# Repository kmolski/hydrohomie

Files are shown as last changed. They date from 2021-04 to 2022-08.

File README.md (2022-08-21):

# hydrohomie

The smart drink coaster that lets you gather, view and analyze data on your water drinking habits.

The coaster device, based on the ESP32 MCU, uses a load sensor to measure the volume of water consumed,
which is then (optionally) sent over Wi-Fi & MQTT to the web application for storage and presentation purposes.

This started out as my 5th semester project for the Microprocessor and Embedded Systems course, for which I
prepared the hardware and firmware components. The web application was created later, primarily as a means to
get some practice with new Java features and popular libraries, like Spring Integration/Security and Mockito.

Project components
------------------

- [Hardware](./hardware) - board & logic schematics in PDF & Autodesk EAGLE files
- [Firmware](./firmware) - firmware for the ESP32 chip, based on the Arduino platform
- [Web application](./web-app) - (optional) Spring Boot web app, provides coaster management & data visualization functionality

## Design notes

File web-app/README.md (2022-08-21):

# hydrohomie - web application


Coverage (https://github.com/kmolski/hydrohomie/actions/workflows/gradle.yml)

Companion web app for the smart coaster device, built with Java 17 and open-source tools.

This application is entirely optional. The smart coaster can function without it, although with
slightly limited functionality (e.g. no measurement/daily total persistence between device restarts).

For more details about the application structure, view the [JavaDocs](https://kmolski.github.io/hydrohomie/docs/).

<p style="text-align: center;">
<table style="padding: 0px; border-spacing: 0px;">
    <tr>
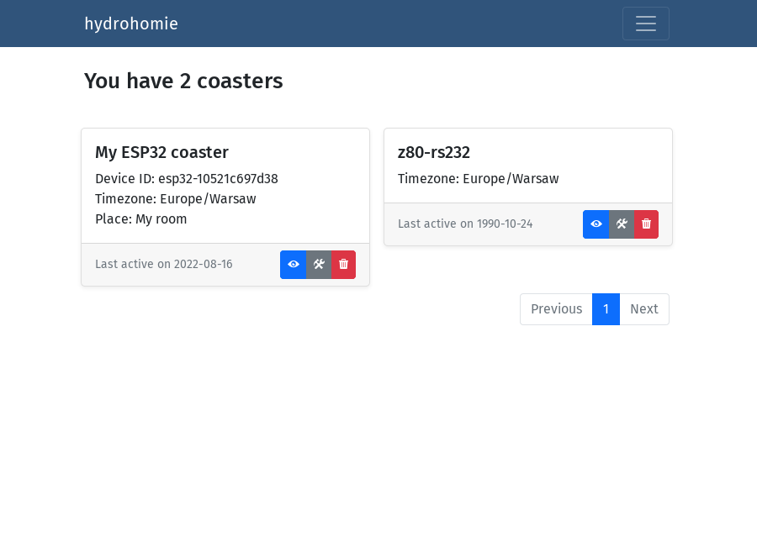
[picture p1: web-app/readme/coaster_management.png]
        <th scope="col"></th>
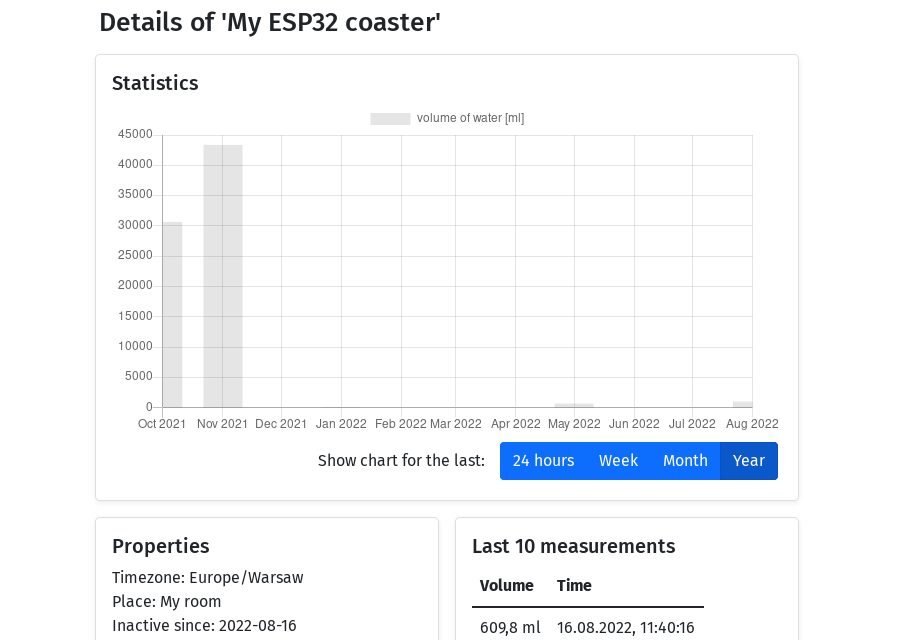
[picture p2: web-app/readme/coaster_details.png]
        <th scope="col"></th>
    </tr>
    <tr>
        <th scope="col">Coaster management</th>
        <th scope="col">Coaster details view</th>
    </tr>
</table>
</p>

Configuration
-------------

| Environment variable | Spring property name | Default value | Description |
|---|---|---|---|
| `ADMIN_USER` | `admin.username` | _(none)_ | Admin account username |
| `ADMIN_PASS` | `admin.password` | _(none)_ | Admin account password |
| `MQTT_URL` | `mqtt.url` | _(none)_ | MQTT broker URL |
| `MQTT_CLIENT_ID` | `mqtt.client-id` | `backend` | MQTT client ID prefix |
| `MQTT_TOPIC` | `mqtt.topic` | `hydrohomie`  | MQTT topic prefix |
| `DB_HOST` | _(none)_ | _(none)_ | PostgreSQL instance hostname |
| `DB_NAME` | _(none)_ | _(none)_ | PostgreSQL database name |
| `DB_USER` | _(none)_ | _(none)_ | PostgreSQL account username  |
| `DB_PASS` | _(none)_ | _(none)_ | PostgreSQL account password  |

Quick setup with docker-compose
-----------

### Build Docker container

```cmd
$ ./gradlew bootBuildImage
```

### Run with docker-compose

__This method uses `admin/admin` as the default admin account credentials.__

```cmd
$ docker-compose up -d
```

The application will be available at `http://localhost:8080`.

First steps
-----------

1. Log in with the admin account
2. Create a new application user 
3. Turn the coaster on & go to the "Coasters" tab
4. Click "Assign" to start the assignment procedure
5. Choose the user account to assign the coaster to
6. Log in with the application user account

Dependencies
------------

- [Spring Boot](https://spring.io/projects/spring-boot) - configuration & monitoring
- [Spring WebFlux](https://docs.spring.io/spring-framework/docs/current/reference/html/web-reactive.html) - reactive Web MVC framework
- [Spring Security](https://spring.io/projects/spring-security) - authentication & access control
- [Spring Integration](https://spring.io/projects/spring-integration) + [Paho client](https://www.eclipse.org/paho) - MQTT communication
- [Thymeleaf](https://www.thymeleaf.org) + [Bootstrap](https://getbootstrap.com) - HTML templates & CSS framework
- [Spring Data R2DBC](https://spring.io/projects/spring-data-r2dbc) + [PostgreSQL](https://www.postgresql.org) - object mapper & RDBMS
- [JUnit 5](https://junit.org/junit5) + [Mockito](https://site.mockito.org) - integration & unit test tools
- [Testcontainers](https://www.testcontainers.org) - containers for integration tests
- [Liquibase](https://www.liquibase.org) - database migration tool
- [Lombok](https://projectlombok.org) - code generation library

License
-------

[MIT License](https://opensource.org/licenses/MIT)

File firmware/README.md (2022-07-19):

# hydrohomie - firmware

Firmware for the smart coaster device, based on the Arduino ESP32 platform and open-source libraries.

Setup instructions
-----------

### Load cell calibration
1. Configure the target device in `platformio.ini`.
2. Uncomment the load cell calibration code at `src/embedded.cpp:163-171`.
3. Build & flash the device with `pio run -t upload`.
4. Wait for the device to start and press S1 with a known weight on the coaster.
5. Write down the value shown on the LCD screen as "x".
6. Calculate the load cell scale as `x / m`, where "m" is the known weight in grams.
7. Set the load cell scale in `include/config.h`.
8. Comment/remove the load cell calibration code.

### Wi-Fi and MQTT configuration
9. Set the Wi-Fi SSID, Wi-Fi password, MQTT broker IP and MQTT topic in `include/secrets.h`.
10. Adjust the maximum inactivity time in `include/config.h`.

### Firmware flashing
11. Build & flash the device with `pio run -t upload`.

Dependencies
------------

- [PlatformIO toolset](https://platformio.org)
- [Arduino ESP32 platform](https://github.com/espressif/arduino-esp32)
- [Arduino LiquidCrystal library](https://www.arduino.cc/en/Reference/LiquidCrystal)
- [Arduino WiFi library](https://www.arduino.cc/en/Reference/WiFi)
- [knolleary/PubSubClient](https://github.com/knolleary/pubsubclient)
- [bblanchon/ArduinoJson](https://github.com/bblanchon/ArduinoJson)
- [bogde/HX711](https://github.com/bogde/HX711)

License
-------

[MIT License](https://opensource.org/licenses/MIT)

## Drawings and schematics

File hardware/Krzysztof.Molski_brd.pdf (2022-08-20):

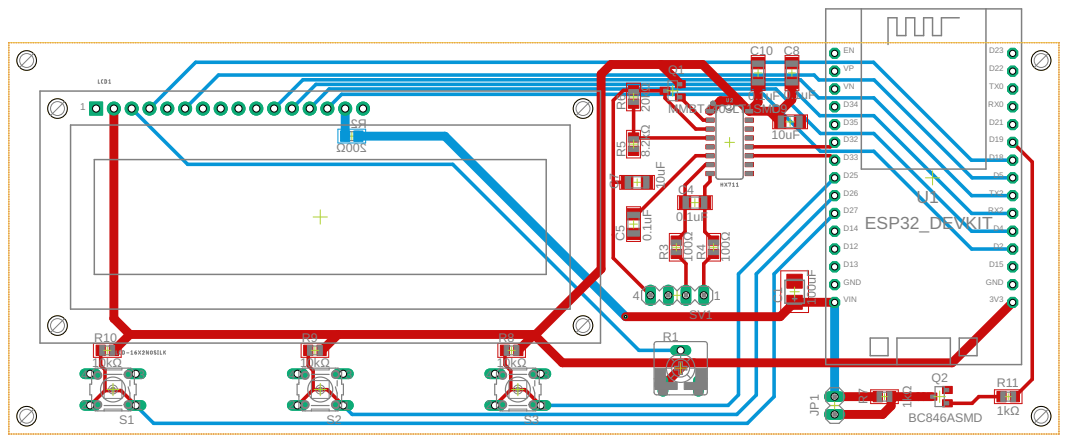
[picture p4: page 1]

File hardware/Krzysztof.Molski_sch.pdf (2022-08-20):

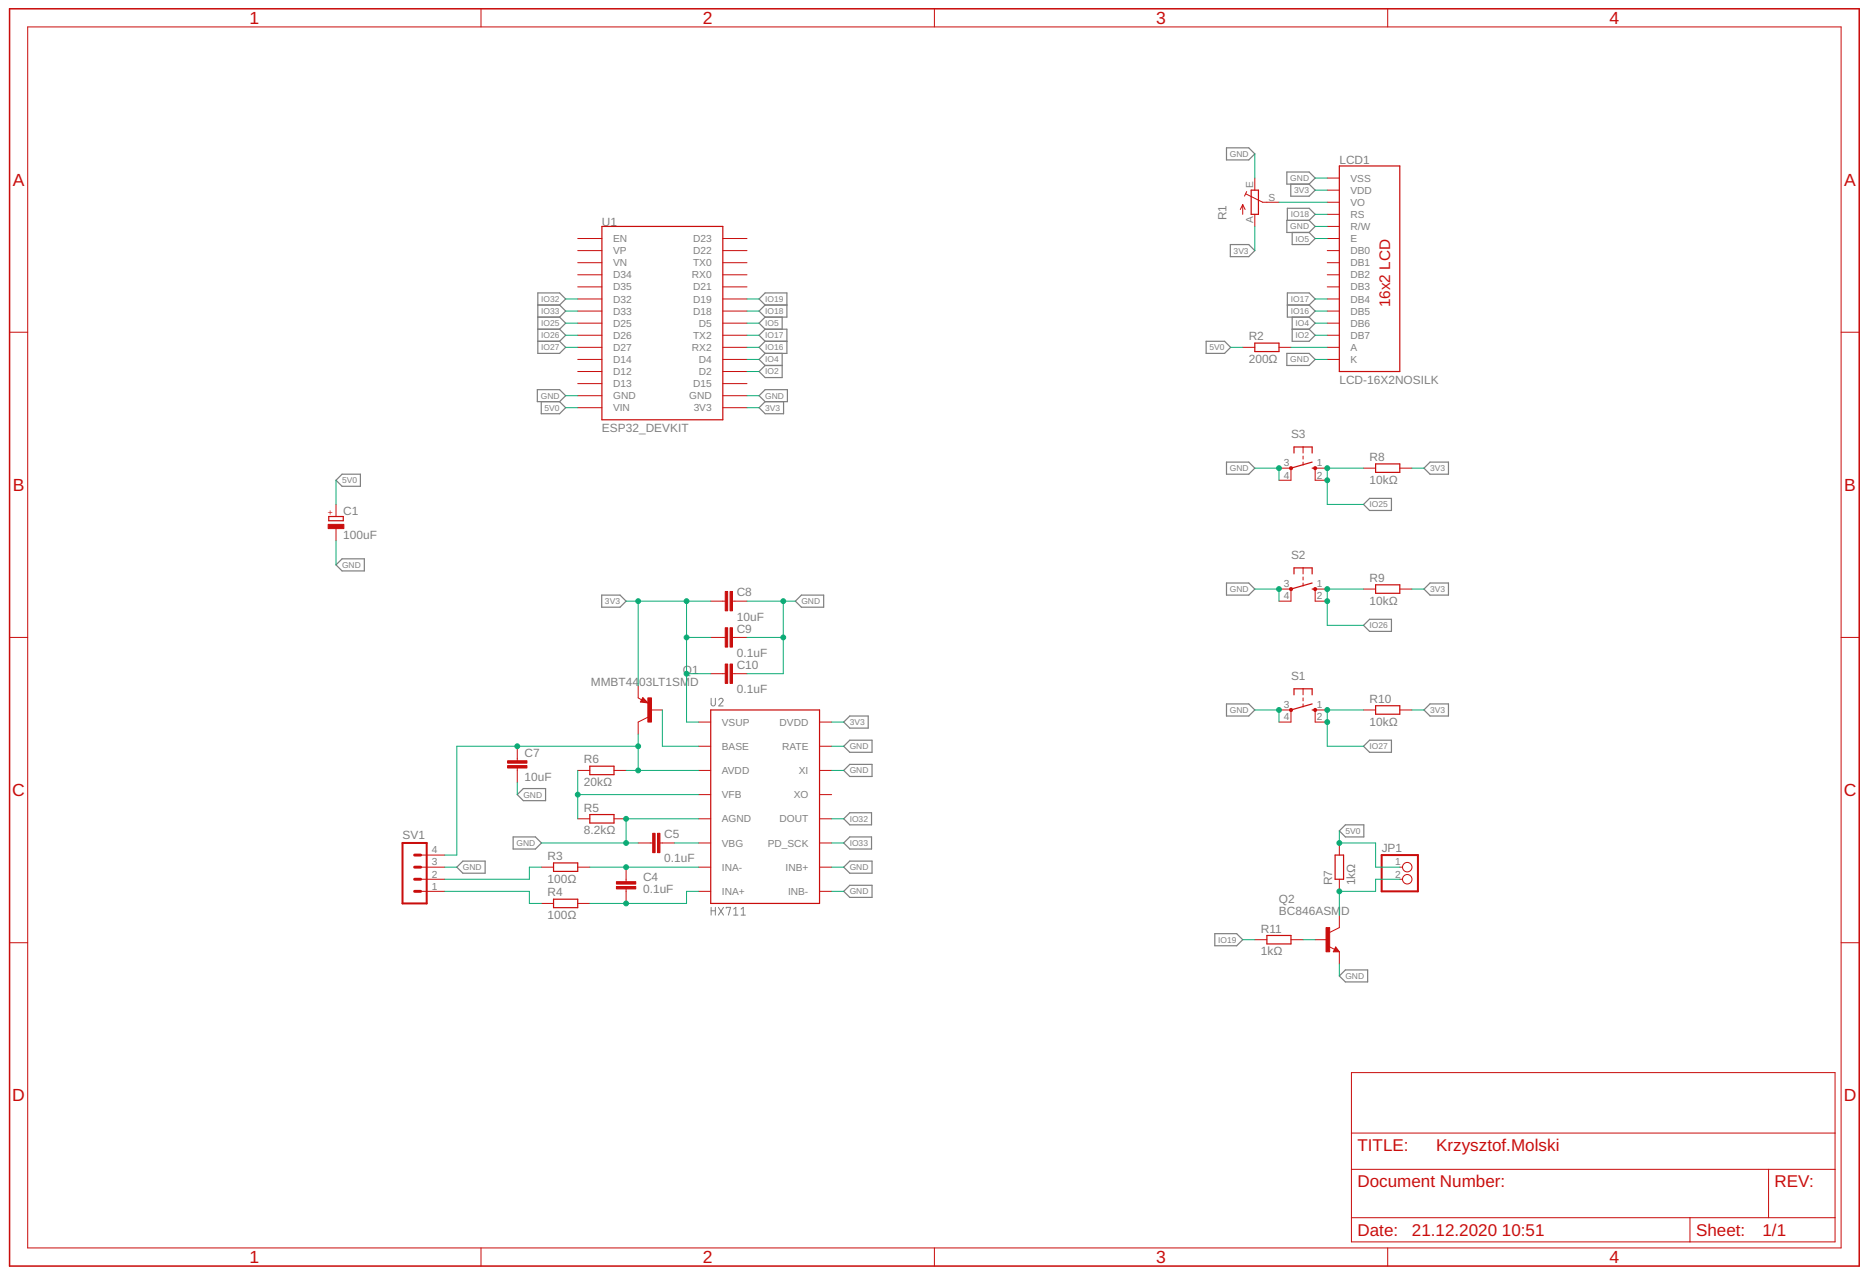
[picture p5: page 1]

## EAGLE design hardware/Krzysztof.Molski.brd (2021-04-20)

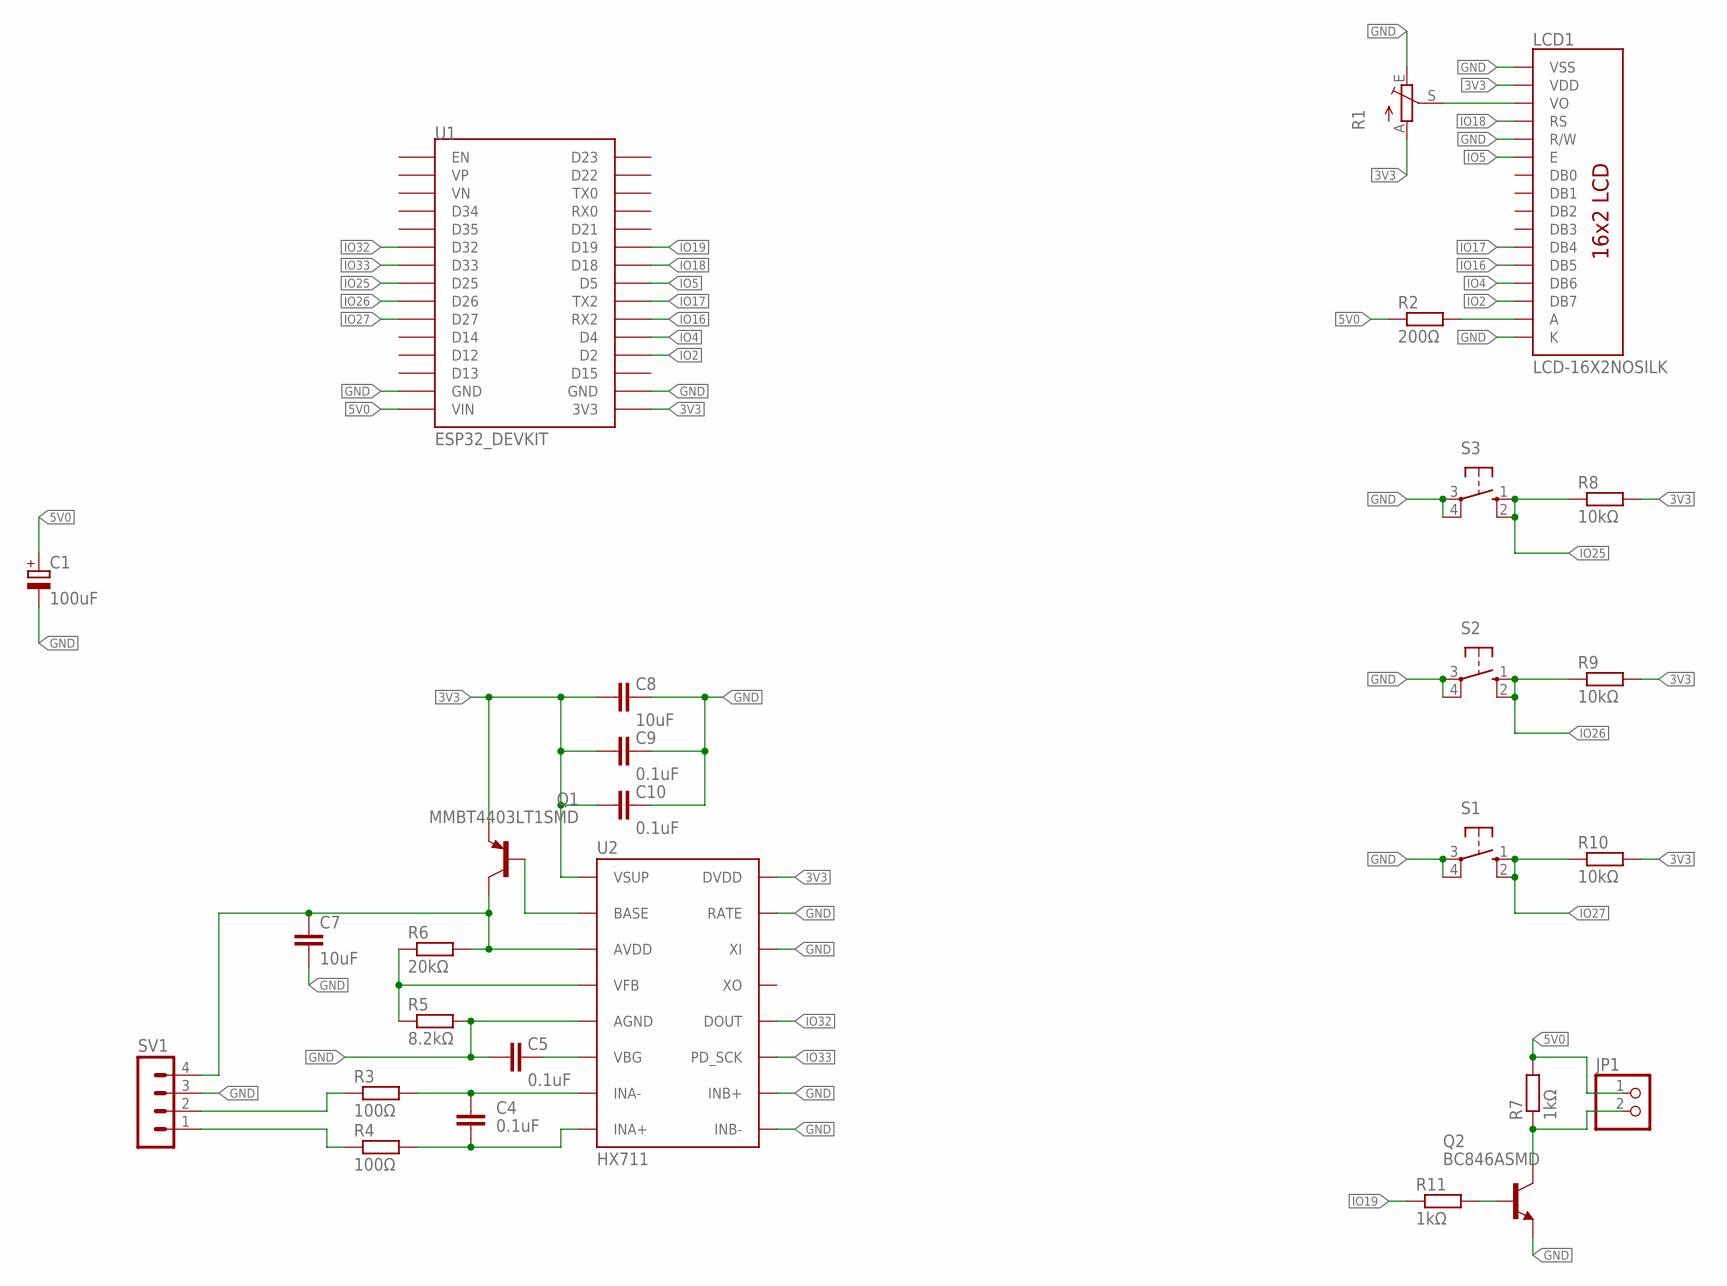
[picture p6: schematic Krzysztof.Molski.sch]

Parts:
C1: 100uF; CT3528
C4, C5, C9, C10: 0.1uF; C1206
C7, C8: 10uF; C1206
JP1: PINHD-1X2; 1X02
LCD1: LCD-16X2NOSILK; LCD-16X2_NOSILK
Q1: MMBT4403LT1SMD; SOT23-BEC
Q2: BC846ASMD; SOT23
R1: TRIM_EU-CA6V; CA6V
R2: 200Ω; R0805
R3, R4: 100Ω; R0805
R5: 8.2kΩ; R0805
R6: 20kΩ; R0805
R7, R11: 1kΩ; R0805
R8, R9, R10: 10kΩ; R0805
S1, S2, S3: 10-XX; B3F-10XX
SV1: MA04-1
U1: ESP32_DEVKIT
U2: HX711; SO16

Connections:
3V3: C8.2, C9.2, C10.2, LCD1.2 (VDD), Q1.E, R1.A, R8.2, R9.2, R10.2, U1.3V3, U2.1 (VSUP), U2.16 (DVDD)
5V0: C1.+, JP1.1, R2.1, R7.2, U1.VIN
GND: C1.-, C5.2, C7.2, C8.1, C9.1, C10.1, LCD1.1 (VSS), LCD1.5 (R/W), LCD1.16 (K), Q2.2 (E), R1.E, R5.2, S1.3, S1.4 (P1), S2.3, S2.4 (P1), S3.3, S3.4 (P1), SV1.3, U1.GND@1 (GND), U1.GND@2 (GND), U2.5 (AGND), U2.9 (INB-), U2.10 (INB+), U2.14 (XI), U2.15 (RATE)
IO2: LCD1.14 (DB7), U1.D2
IO4: LCD1.13 (DB6), U1.D4
IO5: LCD1.6 (E), U1.D5
IO16: LCD1.12 (DB5), U1.RX2
IO17: LCD1.11 (DB4), U1.TX2
IO18: LCD1.4 (RS), U1.D18
IO19: R11.1, U1.D19
IO25: R8.1, S3.1 (S), S3.2 (S1), U1.D25
IO26: R9.1, S2.1 (S), S2.2 (S1), U1.D26
IO27: R10.1, S1.1 (S), S1.2 (S1), U1.D27
IO32: U1.D32, U2.12 (DOUT)
IO33: U1.D33, U2.11 (PD_SCK)
unnamed: C4.1, R4.2, U2.8 (INA+)
unnamed: R3.1, SV1.2
unnamed: LCD1.15 (A), R2.2
unnamed: C4.2, R3.2, U2.7 (INA-)
unnamed: Q1.B, U2.2 (BASE)
unnamed: LCD1.3 (VO), R1.S
unnamed: Q2.1 (B), R11.2
unnamed: R4.1, SV1.1
unnamed: C5.1, U2.6 (VBG)
unnamed: C7.1, Q1.C, R6.2, SV1.4, U2.3 (AVDD)
unnamed: R5.1, R6.1, U2.4 (VFB)
unnamed: JP1.2, Q2.3 (C), R7.1

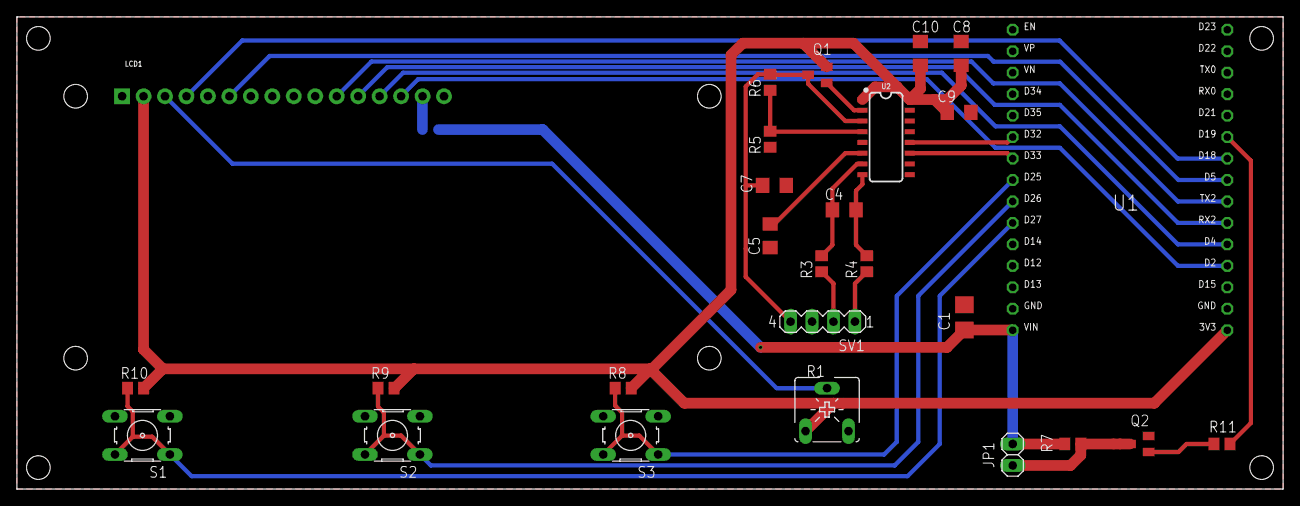
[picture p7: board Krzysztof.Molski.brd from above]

Board: 2 copper layers, 149.9 x 55.9 mm, 28 parts (1 on the bottom side), 27 nets.

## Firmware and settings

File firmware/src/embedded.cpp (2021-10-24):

#include <HX711.h>
#include <LiquidCrystal.h>

#include <ArduinoJson.h>
#include <PubSubClient.h>
#include <WiFi.h>

#include "constants.h"

#include <atomic>
#include <chrono>
#include <mutex>

using namespace std::chrono;

// 16x2 character LCD pin bindings:
// RS = pin 18, EN = pin 5, D4 = pin 17
// D5 = pin 16, D6 = pin 4, D7 = pin 2
LiquidCrystal lcd(18, 5, 17, 16, 4, 2);
// HX711 load sensor bindings:
// Data = pin 32, Clock = pin 33
HX711 scale;

WiFiClient wifi_client;
PubSubClient mqtt_client{wifi_client};

// MQTT client ID for the device, based on the MAC address (eg. 'esp32-a0b0c0d0e0f0')
char device_name[DEVICE_NAME_LEN] = {0};
// MQTT device topic, based on the client ID (eg. 'app/device/esp32-a0b0c0d0e0f0')
char device_topic[DEVICE_TOPIC_LEN] = {0};

steady_clock st_clock;
time_point<steady_clock> last_activity;
std::mutex time_mutex; // protects last_activity

TaskHandle_t buzzer_task;
void buzzerTask(void *) {
    // Buzzer is on pin 19, LOW is off, HIGH is on
    bool buzzer_state = LOW;
    while (true) {
        time_mutex.lock();
        if (st_clock.now() - last_activity > MAX_INACTIVE_TIME) {
            buzzer_state = !buzzer_state;
        } else {
            buzzer_state = LOW;
        }
        time_mutex.unlock();

        digitalWrite(19, buzzer_state);
        delay(1000);
    }
}

std::atomic<float> last_load, load, total{0.0}, first_weight{0.0};
std::atomic<bool> request_tare{false};

TaskHandle_t load_cell_task;
void loadCellTask(void *) {
    while (true) {
        bool tare_requested = true;
        request_tare.compare_exchange_strong(tare_requested, false);
        if (tare_requested) {
            scale.tare();
        }

        last_load = float(load);
        load = scale.get_units(10);

        if (abs(last_load - load) > 10.0) {
            time_mutex.lock();
            last_activity = st_clock.now();
            time_mutex.unlock();
        }

        delay(50);
    }
}

enum class CoasterState { IDLE, MEASURE_FIRST, FIRST_COMPLETE, DISCARD, MEASURE_SECOND, SECOND_COMPLETE, STORE_RESULT };

CoasterState current_state{CoasterState::IDLE};

void subscriptionCallback(char topic[], byte *payload, unsigned int length) {
    JsonDoc doc;
    if (strcmp(topic, device_topic) == 0) {
        deserializeJson(doc, payload, length);

        const char *message_type = doc["type"].as<char *>();
        if (strcmp("listening", message_type) == 0) {
            total = doc["initTotal"].as<float>();

            JsonVariant init_load = doc["initLoad"].as<JsonVariant>();
            if (!init_load.isNull()) {
                current_state = CoasterState::FIRST_COMPLETE;
                first_weight = init_load.as<float>();
            }
        }
    }
}

TaskHandle_t heartbeat_task;
void heartbeatTask(void *) {
    byte json_bytes[1024] = {0};

    while (true) {
        if (mqtt_client.connected()) {
            time_mutex.lock();
            int inactive_seconds = duration_cast<seconds>(st_clock.now() - last_activity).count();
            time_mutex.unlock();

            JsonDoc doc;
            doc["device"] = device_name;
            doc["type"] = "heartbeat";
            doc["inactiveSeconds"] = inactive_seconds;

            size_t n_bytes = serializeJson(doc, json_bytes);
            mqtt_client.publish(device_topic, json_bytes, n_bytes);
        }

        delay(2 * 60 * 1000);
    }
}

TaskHandle_t connection_task;
void connectionTask(void *) {
    byte json_bytes[1024] = {0};

    while (true) {
        if (!mqtt_client.connected() && mqtt_client.connect(device_name)) {
            mqtt_client.subscribe(device_topic);

            JsonDoc doc;
            doc["device"] = device_name;
            doc["type"] = "connected";

            size_t n_bytes = serializeJson(doc, json_bytes);
            mqtt_client.publish(MQTT_TOPIC, json_bytes, n_bytes);
        }

        delay(5000);
    }
}

// Button 1 = pin 27, button 2 = pin 26, button 3 = pin 25
std::atomic<bool> button1{false}, button2{false}, button3{false};

void IRAM_ATTR button1ISR() { button1 = (digitalRead(27) == LOW); }
void IRAM_ATTR button2ISR() { button2 = (digitalRead(26) == LOW); }
void IRAM_ATTR button3ISR() { button3 = (digitalRead(25) == LOW); }

void setup() {
    lcd.begin(16, 2);
    scale.begin(32, 33);

    pinMode(25, INPUT);
    attachInterrupt(digitalPinToInterrupt(25), button3ISR, CHANGE);
    pinMode(26, INPUT);
    attachInterrupt(digitalPinToInterrupt(26), button2ISR, CHANGE);
    pinMode(27, INPUT);
    attachInterrupt(digitalPinToInterrupt(27), button1ISR, CHANGE);

    // Load cell calibration code (uncomment on first startup)
    // scale.set_scale();
    // scale.tare();
    // lcd.setCursor(0, 0);
    // lcd.print("Place a weight and press S1.");
    // while (digitalRead(27) == HIGH);
    //
    // lcd.setCursor(0, 0);
    // lcd.print(scale.get_units(10));
    // while (digitalRead(27) == HIGH);

    pinMode(19, OUTPUT);
    digitalWrite(19, LOW);
    last_activity = st_clock.now();
    xTaskCreatePinnedToCore(buzzerTask, "buzzer task", 1000, NULL, 1, &buzzer_task, 1);

    // After calculating the load cell scale, adjust it in config.h
    scale.set_scale(LOAD_CELL_SCALE);
    scale.tare();
    xTaskCreatePinnedToCore(loadCellTask, "load cell task", 1000, NULL, 1, &load_cell_task, 1);

    byte mac[6] = {0};
    WiFi.macAddress(mac);
    snprintf(device_name, DEVICE_NAME_LEN, "esp32-%x%x%x%x%x%x", mac[0], mac[1], mac[2], mac[3], mac[4], mac[5]);
    snprintf(device_topic, DEVICE_TOPIC_LEN, "%s%s%s", MQTT_TOPIC, MQTT_DEVICE_TOPIC_SUFFIX, device_name);

    // Adjust WiFi credentials in secrets.h
    WiFi.begin(WIFI_SSID, WIFI_PASS);
    while (WiFi.status() != WL_CONNECTED) {
        delay(100);
    }

    // Adjust MQTT config in secrets.h
    mqtt_client.setServer(MQTT_SERVER_IP, 1883);
    mqtt_client.setCallback(subscriptionCallback);

    xTaskCreatePinnedToCore(heartbeatTask, "heartbeat task", 4000, NULL, 1, &heartbeat_task, 0);
    xTaskCreatePinnedToCore(connectionTask, "connection task", 4000, NULL, 1, &connection_task, 0);
}

char statusToChar(int state) {
    switch (state) {
        case MQTT_CONNECTED:
            return 'C';
        case MQTT_DISCONNECTED:
            return 'D';
        default:
            return 'N';
    }
}

void loop() {
    byte json_bytes[1024] = {0};

    mqtt_client.loop();

    char line_buf[17] = {0};
    lcd.setCursor(0, 1);

    time_mutex.lock();
    if (st_clock.now() - last_activity > MAX_INACTIVE_TIME) {
        lcd.print("Inactive for 1hr");
    } else {
        snprintf(line_buf, 17, "T:%6.1lfml %c:%+3d", float(total), statusToChar(mqtt_client.state()), WiFi.RSSI());
        lcd.print(line_buf);
    }

    int min_since_active = duration_cast<minutes>(st_clock.now() - last_activity).count();
    int hours = min_since_active / 60;
    int minutes = min_since_active % 60;
    time_mutex.unlock();

    switch (current_state) {
        case CoasterState::IDLE: {
            snprintf(line_buf, 17, "L:%7.2fg %02d:%02d", float(load), hours, minutes);
            lcd.setCursor(0, 0);
            lcd.print(line_buf);

            if (button1) {
                current_state = CoasterState::MEASURE_FIRST;

                time_mutex.lock();
                last_activity = st_clock.now();
                time_mutex.unlock();

                first_weight = float(load);
                lcd.setCursor(0, 0);
                lcd.print("S:");

                JsonDoc doc;
                doc["device"] = device_name;
                doc["type"] = "begin";
                doc["load"] = float(first_weight);

                size_t n_bytes = serializeJson(doc, json_bytes);
                mqtt_client.publish(device_topic, json_bytes, n_bytes);

                delay(2000);
                current_state = CoasterState::FIRST_COMPLETE;
            }

            if (button2) {
                total = 0.0;
                lcd.setCursor(0, 0);
                lcd.print("Total cleared.  ");
                delay(1000);
            }
            break;
        }

        case CoasterState::FIRST_COMPLETE: {
            float second_weight = load;
            float volume = (first_weight - second_weight) / WATER_DENSITY;

            snprintf(line_buf, 17, "D:%6.1lfml %02d:%02d", volume, hours, minutes);
            lcd.setCursor(0, 0);
            lcd.print(line_buf);

            if (button1) {
                current_state = CoasterState::MEASURE_SECOND;
                lcd.setCursor(0, 0);
                lcd.print("V:");

                float old_total = float(total);
                float new_total = old_total + volume;
                while (!total.compare_exchange_strong(old_total, new_total)) {
                    new_total = old_total + volume;
                }

                JsonDoc doc;
                doc["device"] = device_name;
                doc["type"] = "end";
                doc["volume"] = volume;

                size_t n_bytes = serializeJson(doc, json_bytes);
                mqtt_client.publish(device_topic, json_bytes, n_bytes);

                delay(2000);
                current_state = CoasterState::IDLE;
            }

            if (button2) {
                current_state = CoasterState::DISCARD;
                lcd.setCursor(0, 0);
                lcd.print("Drink discarded.");

                JsonDoc doc;
                doc["device"] = device_name;
                doc["type"] = "discard";

                size_t n_bytes = serializeJson(doc, json_bytes);
                mqtt_client.publish(device_topic, json_bytes, n_bytes);

                delay(1000);
                current_state = CoasterState::IDLE;
            }
            break;
        }

        default:
            break;
    }

    if (button3) {
        lcd.setCursor(0, 0);
        lcd.print("Calibrating...  ");
        request_tare = true;
        delay(1000);
    }

    delay(100);
}

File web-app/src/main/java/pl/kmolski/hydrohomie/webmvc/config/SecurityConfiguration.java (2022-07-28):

package pl.kmolski.hydrohomie.webmvc.config;

import org.springframework.context.annotation.Bean;
import org.springframework.context.annotation.Configuration;
import org.springframework.security.config.annotation.web.reactive.EnableWebFluxSecurity;
import org.springframework.security.config.web.server.ServerHttpSecurity;
import org.springframework.security.crypto.argon2.Argon2PasswordEncoder;
import org.springframework.security.crypto.password.PasswordEncoder;
import org.springframework.security.web.server.SecurityWebFilterChain;
import org.springframework.security.web.server.authentication.RedirectServerAuthenticationSuccessHandler;
import org.springframework.security.web.server.authentication.logout.RedirectServerLogoutSuccessHandler;
import pl.kmolski.hydrohomie.account.model.AccountRole;

/**
 * Global web security and password encoding configuration.
 */
@Configuration
@EnableWebFluxSecurity
public class SecurityConfiguration {

    private static final int SALT_LENGTH = 16;
    private static final int HASH_LENGTH = 32;
    private static final int PARALLELISM = 1;
    private static final int MEMORY = 1 << 14;
    private static final int ITERATIONS = 4;

    /**
     * Configure the Argon2id password encoder, as recommended by the
     * <a href="https://cheatsheetseries.owasp.org/cheatsheets/Password_Storage_Cheat_Sheet.html">OWASP Cheat Sheet</a>
     *
     * @return password encoder using the Argon2id algorithm
     */
    @Bean
    public PasswordEncoder passwordEncoder() {
        return new Argon2PasswordEncoder(SALT_LENGTH, HASH_LENGTH, PARALLELISM, MEMORY, ITERATIONS);
    }

    /**
     * Configure the Spring {@link SecurityWebFilterChain}.
     * @param http the web security configurator
     * @return the configured {@link SecurityWebFilterChain} instance
     */
    @Bean
    public SecurityWebFilterChain securityWebFilterChain(ServerHttpSecurity http) {
        return http.authorizeExchange()
                .pathMatchers("/actuator/health").permitAll()
                .pathMatchers("/login", "/webjars/**").permitAll()
                .pathMatchers("/admin/**").hasAuthority(AccountRole.ROLE_ADMIN.name())
                .pathMatchers("/user/**").hasAuthority(AccountRole.ROLE_USER.name())
                .pathMatchers("/**").authenticated()
                    .and()
                .formLogin()
                    .loginPage("/login")
                    .authenticationSuccessHandler(new RedirectServerAuthenticationSuccessHandler("/"))
                    .and()
                .logout()
                    .logoutUrl("/logout")
                    .logoutSuccessHandler(new RedirectServerLogoutSuccessHandler())
                    .and()
                .build();
    }
}

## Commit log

2021-01-23 Embedded code prototype with MQTT conn
2021-04-19 Clean up Arduino project files
2021-04-20 Add EAGLE board and schematic files
    [Krzysztof.Molski.brd, Krzysztof.Molski.sch]
2021-06-23 Add CAM output (Gerber+drill+assembly) board files
    [copper_bottom.gbr, copper_top.gbr, drill_1_16.xln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]
2021-07-29 Add Spring Boot web application
2021-09-12 Add MQTT device topic handler
2021-10-08 Working MQTT flow for connected->listening interaction
2021-10-10 Migrate measurements to zoned datetime, add logic for device topic messages
2021-10-12 Pass current time/date in arguments
2021-10-17 Fix MQTT disconnect on send, inactive_since default value
    Inbound and outbound MQTT clients now have different client IDs, ending with "-rx" and "-tx" respectively. The inactiveSince coaster field is now initialized with the current time.
2021-10-21 Improve time handling with clock DI
    CoasterRepository::create now takes an Instant parameter for inactive_since. All CoasterService methods now take Instant parameters for the current time.
2021-10-21 Update last_activity on drink start in firmware.
    Following the web app change, the time since last activity will be reset when the drink is started.
    [embedded.cpp]
2021-10-24 Improve MQTT reconnect handling
    Restarting the MQTT broker connection no longer hangs the user interface.
    [embedded.cpp]
2022-05-07 Fix circular dependency, refactor if instanceof chain
2022-06-16 Update Spring Boot, add Thymeleaf extras & Argon2 library
2022-06-16 Move packages, fix CSRF token in login form, use Argon2 hashing
    [AdminAccount.java, SecurityConfiguration.java]
2022-07-03 Add Spring Validation and NewUserDto
2022-07-26 Add integration test for DeviceTopicHandler
2022-07-28 Adjust wait times in DeviceTopicHandlerIT, argon2id params
2022-08-20 Add board and electronic schematics
2022-08-20 Bump version, remove JavaDoc errors
    [AdminAccount.java]
